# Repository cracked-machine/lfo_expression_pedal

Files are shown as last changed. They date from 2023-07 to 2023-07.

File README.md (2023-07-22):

## Docker

This project uses the [stm32_dev_docker](https://github.com/cracked-machine/stm32_dev_docker) project to host the developnment environment. Please read the documentation for that project for more information.

## Power consumption

- Power supply voltage: 9V
- LDO Regulator ([AMS1117-3.3](https://datasheet.lcsc.com/lcsc/2204131745_Shenzhen-Fuman-Elec-AMS1117-3-3V_C173386.pdf)): 3.3V
- Power Dissipation (quiescent): 0.034W

## Outputs

|S (sleeve)|T (tip)|R (ring)|
|-|-|-|
|Ground|Signal|3.3V|

## Changelog

### PCB

- REVB
    - Add 3.3v to U1 VREF+ (Pin5).
    -

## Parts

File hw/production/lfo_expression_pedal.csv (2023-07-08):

Reference | Value | Footprint | Datasheet | Field5 | LCSC MPN | Qty
C1, C3, C7, C8 | 100nF | Capacitor_SMD:C_0805_2012Metric_Pad1.18x1.45mm_HandSolder | https://datasheet.lcsc.com/lcsc/2201271030_YAGEO-CC0805KRX7R6BB104_C1852967.pdf |  | C1852967 | 4
C2 | 4.7uF | Capacitor_SMD:C_0805_2012Metric_Pad1.18x1.45mm_HandSolder | https://datasheet.lcsc.com/lcsc/2208151830_Walsin-Tech-Corp-0805F475Z100CT_C5122271.pdf |  | C967590 | 1
C4 | 1uF | Capacitor_SMD:C_0805_2012Metric_Pad1.18x1.45mm_HandSolder | https://datasheet.lcsc.com/lcsc/1810191224_Samsung-Electro-Mechanics-CL21B105KPFNNNE_C107367.pdf |  | C107367 | 1
C5, C6 | 10uF | Capacitor_SMD:C_0805_2012Metric_Pad1.18x1.45mm_HandSolder | https://datasheet.lcsc.com/lcsc/2210281800_VIIYONG-V106K0805X5R250NHP_C5240379.pdf |  | C5240379 | 2
J1 | Conn_02x05_Odd_Even | Connector_PinHeader_1.27mm:PinHeader_2x05_P1.27mm_Vertical_SMD | https://datasheet.lcsc.com/lcsc/2201121700_XFCN-PZ127VS-12-10-H10-A38_C2935458.pdf |  | C2935458 | 1
J2, J6 | Conn_01x03 | Connector_PinHeader_2.54mm:PinHeader_1x03_P2.54mm_Vertical | ~ |  |  | 2
J4 | Conn_01x02 | Connector_PinHeader_2.54mm:PinHeader_1x02_P2.54mm_Vertical | ~ |  |  | 1
J5 | Conn_01x04 | Connector_PinHeader_2.54mm:PinHeader_1x04_P2.54mm_Vertical | ~ |  |  | 1
R1, R2 | 4.7k | Resistor_SMD:R_0805_2012Metric_Pad1.20x1.40mm_HandSolder | https://datasheet.lcsc.com/lcsc/2205131800_VO-SCR0805J4K7_C3017854.pdf |  | C3017854 | 2
R3, R5 | DNF | Resistor_SMD:R_0805_2012Metric_Pad1.20x1.40mm_HandSolder | ~ |  |  | 2
R4, R6 | 0R | Resistor_SMD:R_0805_2012Metric_Pad1.20x1.40mm_HandSolder | https://datasheet.lcsc.com/lcsc/2111021130_FOJAN-FRC0805P000-TS_C2907288.pdf |  | C2907288 | 2
R10 | 10k | Resistor_SMD:R_0805_2012Metric_Pad1.20x1.40mm_HandSolder | https://datasheet.lcsc.com/lcsc/2304140030_RALEC-RTT05103JTP_C103914.pdf |  | C103914 | 1
SW1-SW4 | SW_SPST | Button_Switch_THT:SW_PUSH_6mm | ~ |  |  | 4
SW5 | SW_SPST | Connector_PinSocket_2.54mm:PinSocket_1x02_P2.54mm_Vertical | ~ |  |  | 1
SW6 | RotaryEncoder_Switch | Rotary_Encoder:RotaryEncoder_Alps_EC12E-Switch_Vertical_H20mm | ~ |  |  | 1
TP1-TP4 | TestPoint | TestPoint:TestPoint_Pad_1.0x1.0mm | ~ |  |  | 4
U1 | STM32G071CBU3 | Package_DFN_QFN:QFN-48-1EP_7x7mm_P0.5mm_EP5.6x5.6mm | https://www.st.com/resource/en/datasheet/stm32g071cb.pdf |  | C724076 | 1
U2 | LM1117MP-3.3 | Package_TO_SOT_SMD:SOT-223-3_TabPin2 | https://datasheet.lcsc.com/lcsc/2204131745_Shenzhen-Fuman-Elec-AMS1117-3-3V_C173386.pdf |  | C173386 | 1
U3, U4 | AS321KTR-G1 | Package_TO_SOT_SMD:SOT-23-5 | https://datasheet.lcsc.com/lcsc/1809191840_Diodes-Incorporated-AS321KTR-G1_C144156.pdf |  | C144156 | 2

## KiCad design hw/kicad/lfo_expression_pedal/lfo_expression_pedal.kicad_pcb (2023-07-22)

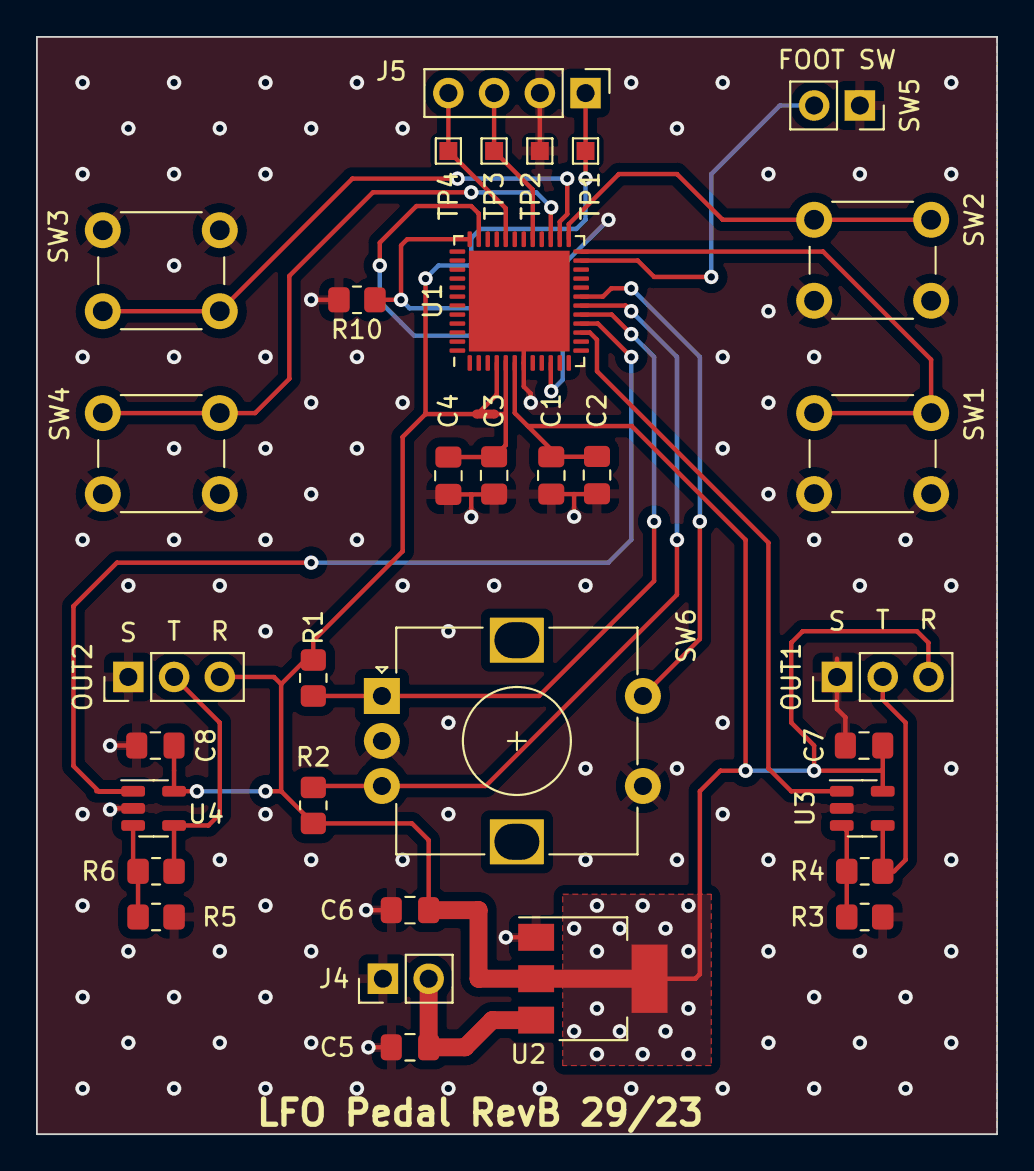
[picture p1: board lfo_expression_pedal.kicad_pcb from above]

Board: 2 copper layers, 53.3 x 61.0 mm, 35 parts (1 on the bottom side), 23 nets.

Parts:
C1, C3, C7, C8: 100nF; C_0805_2012Metric_Pad1.18x1.45mm_HandSolder
C2: 4.7uF; C_0805_2012Metric_Pad1.18x1.45mm_HandSolder
C4: 1uF; C_0805_2012Metric_Pad1.18x1.45mm_HandSolder
C5, C6: 10uF; C_0805_2012Metric_Pad1.18x1.45mm_HandSolder
J1: Conn_02x05_Odd_Even; PinHeader_2x05_P1.27mm_Vertical_SMD
J2, J6: Conn_01x03; PinHeader_1x03_P2.54mm_Vertical
J4: Conn_01x02; PinHeader_1x02_P2.54mm_Vertical
J5: Conn_01x04; PinHeader_1x04_P2.54mm_Vertical
NT1: NetTie_2; NetTie-2_SMD_Pad0.5mm
R1, R2: 4.7k; R_0805_2012Metric_Pad1.20x1.40mm_HandSolder
R3, R5: DNF; R_0805_2012Metric_Pad1.20x1.40mm_HandSolder
R4, R6: 0R; R_0805_2012Metric_Pad1.20x1.40mm_HandSolder
R10: 10k; R_0805_2012Metric_Pad1.20x1.40mm_HandSolder
SW1, SW2, SW3, SW4: SW_SPST; SW_PUSH_6mm
SW5: SW_SPST; PinSocket_1x02_P2.54mm_Vertical
SW6: RotaryEncoder_Switch; RotaryEncoder_Alps_EC12E-Switch_Vertical_H20mm
TP1, TP2, TP3, TP4: TestPoint; TestPoint_Pad_1.0x1.0mm
U1: STM32G071CBU3; QFN-48-1EP_7x7mm_P0.5mm_EP5.6x5.6mm
U2: LM1117MP-3.3; SOT-223-3_TabPin2
U3, U4: AS321KTR-G1; SOT-23-5

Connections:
+3.3V: C1.1, C2.1, C6.1, C7.1, C8.1, J1.1, J2.3, J5.1, J6.3, NT1.2, R1.1, R2.1, TP1.1, U1.4 (VBAT), U1.6 (VDD), U2.2 (VO), U3.5 (V+), U4.5 (V+)
/dac1_out1: U1.15 (PA4), U3.1 (+)
/dac1_out1_buffered: J6.2, R4.2, U3.4
/dac1_out2: U1.16 (PA5), U4.1 (+)
/dac1_out2_buffered: J2.2, R6.2, U4.4
/foot_sw: SW5.2 (B), U1.23 (PB11)
/i2c1_scl: J5.3, TP3.1, U1.29 (PA9/UCPD1_DBCC1)
/i2c1_sda: J5.4, TP4.1, U1.32 (PA10/UCPD1_DBCC2)
/reset: J1.10, U1.10 (PF2)
/rot_enc_sw: SW6.S1, U1.19 (PB0)
/sys_swclk: J1.4, R10.1, U1.36 (PA14)
/sys_swdio: J1.2, U1.35 (PA13)
/tim3_ch1: R1.2, SW6.A, U1.17 (PA6)
/tim3_ch2: R2.2, SW6.B, U1.18 (PA7)
/user_sw1: SW1.2 (B), U1.24 (PB12)
/user_sw2: SW2.2 (B), U1.25 (PB13)
/user_sw3: SW3.2 (B), U1.26 (PB14)
/user_sw4: SW4.2 (B), U1.27 (PB15)
/vref: C3.1, C4.1, NT1.1, U1.5 (VREF+)
GND: C1.2, C2.2, C3.2, C4.2, C5.2, C6.2, C7.2, C8.2, J1.3, J1.5, J1.9, J2.1, J4.1, J5.2, J6.1, R3.2, R5.2, R10.2, SW1.1 (A), SW2.1 (A), SW3.1 (A), SW4.1 (A), SW5.1 (A), SW6.C, SW6.S2, TP2.1, U1.7 (VSS), U1.49 (VSS), U2.1 (GND), U3.2 (V-), U4.2 (V-)
unnamed: C5.1, J4.2, U2.3 (VI)
unnamed: R3.1, R4.1, U3.3 (-)
unnamed: R5.1, R6.1, U4.3 (-)

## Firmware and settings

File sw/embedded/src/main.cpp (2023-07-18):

#include <stm32g071xx.h>
#include <main.hpp>
#include <timer_manager.hpp>

constexpr auto delay_microsecond = stm32::TimerManager::delay_microsecond;
constexpr auto delay = stm32::delay_millisecond;

void setup()
{

    // RCC
        // enable HSI16
        RCC->CR |= RCC_CR_HSION_Msk;
        while((RCC->CR & RCC_CR_HSIRDY) == 0) { } 
        // No div at HSISYS prescaler, 
        RCC->CR &= ~RCC_CR_HSIDIV_Msk;
        // select SYSCLK source as HSISYS, no div for AHB/APB prescalers
        RCC->CFGR &= ~RCC_CFGR_SW_Msk;
        RCC->CFGR &= ~RCC_CFGR_PPRE_Msk;
        RCC->CFGR &= ~RCC_CFGR_HPRE_Msk;
        
        SysTick_Config(SystemCoreClock / 1000U);
        // NVIC_SetPriority(SysTick_IRQn, 3U);
    
    // TIM15 (APB) for DAC trigger
        RCC->APBENR2 |= RCC_APBENR2_TIM15EN_Msk;    // enable clock for TIM15
        TIM15->CR2 |= TIM_CR2_MMS_1;                // TRGO = 0x20 -> Update Event
        TIM15->CR1 |= TIM_CR1_ARPE_Msk;             // Enable preload (more stable to runtime frequency updates)
        TIM15->CNT = 0;                             // Initialise the counter to zero
        TIM15->PSC = 1;                             // Set the prescaler
        TIM15->ARR = 512;                          // Set the auto reload threshold
        // NVIC_EnableIRQ(TIM15_IRQn);
        // NVIC_SetPriority(TIM15_IRQn, 0U);
        TIM15->CR1 |= TIM_CR1_CEN_Msk;

    // DAC (APB) 
        RCC->APBENR1 |= RCC_APBENR1_DAC1EN_Msk;
        DAC->CR = 0;
        DAC->MCR |= DAC_MCR_MODE1_1;    // buffer disabled
        DAC->CR |= DAC_CR_TEN1_Msk;     // trigger enable
        DAC->CR |= DAC_CR_TSEL1_3;      // 0x1000 -> dac_ch1_trg8 interconnect -> TIM15 trigger
        DAC->CR |= DAC_CR_WAVE1_1;      // triagle waveform enabled
        DAC->CR |= (DAC_CR_MAMP1_0 | DAC_CR_MAMP1_3);    // maximum amplitude!
        DAC->CR |= DAC_CR_EN1_Msk;      // enable the DAC output on channel 1


    // TIM17 (APB) for delay
        // RCC->APBENR2 |= RCC_APBENR2_TIM17EN_Msk;
        // stm32::TimerManager::initialise(TIM17);
        // TIM17->PSC = 1;
        // TIM17->ARR = 1024;
        // TIM17->DIER |= TIM_DIER_UIE_Msk;
        // NVIC_EnableIRQ(TIM17_IRQn);
        // NVIC_SetPriority(TIM17_IRQn, 0U);
        // TIM17->CR1 |= TIM_CR1_CEN_Msk;
    
    // TIM3 (APB) for rotary encoder
        RCC->APBENR1 |= RCC_APBENR1_TIM3EN_Msk;
        

    // EXTI (AHB) for foot switch/user buttons

    // I2C1 (APB) for OLED display

}

int main()
{
    setup();
    while (1)
    {
        // delay(2000);
        // DAC->SWTRIGR |= DAC_SWTRIGR_SWTRIG1_Msk;
    }

}

void TIM17_IRQHandler()
{
    // clear the interrupt status flag
    TIM17->SR &= ~TIM_SR_UIF_Msk;
}


void TIM15_IRQHandler()
{
    // clear the interrupt status flag
    TIM15->SR &= ~TIM_SR_UIF_Msk;
}

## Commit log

2023-07-08 add submodule for stm32 docker images
2023-07-08 add kicad hw project
    [lfo_expression_pedal.kicad_pcb, lfo_expression_pedal.kicad_sch]
2023-07-08 add hw production files
    [lfo_expression_pedal-B_Cu.gbr, lfo_expression_pedal-B_Mask.gbr, lfo_expression_pedal-B_Paste.gbr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]
2023-07-08 readme updated with power consumption and out pins notes
2023-07-09 added low level interrupt functions
2023-07-09 added sysmem(_sbrk) and interrupts source files
2023-07-22 Add 3.3v to U1 VREF+ (Pin5)
    [lfo_expression_pedal.kicad_pcb, lfo_expression_pedal.kicad_sch]
